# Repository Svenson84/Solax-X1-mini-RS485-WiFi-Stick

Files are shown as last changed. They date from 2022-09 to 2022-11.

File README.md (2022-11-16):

# Solax-X1-mini-RS485-WiFi-Stick

RS485 WiFi Stick is a project to monitor the Solax X1 mini via RS485 interface.  
Optional data can be stored in a InfluxDB.

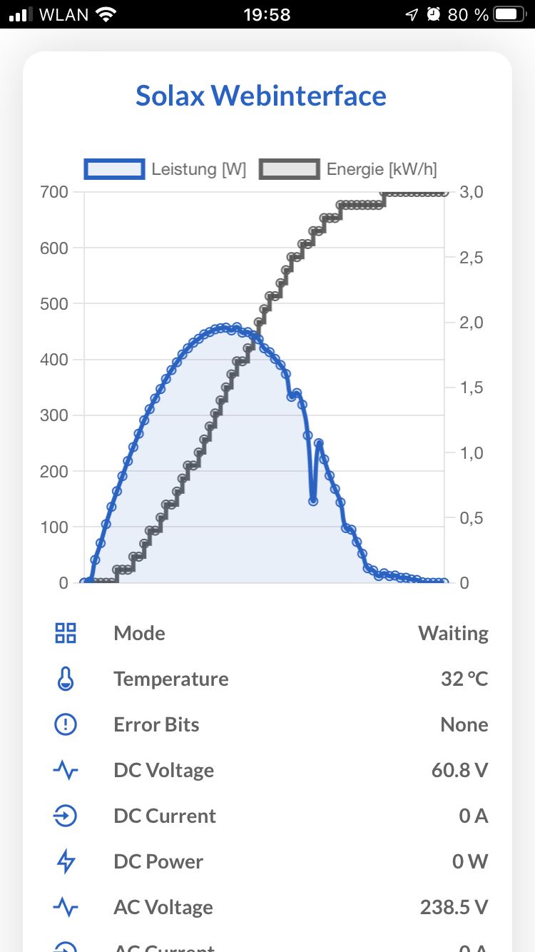
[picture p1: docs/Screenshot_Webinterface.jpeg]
Webinterface


## What it does and what it doesn't?
This software provides a local webinterface via a wifi connection for the "Solax X1 Mini" power inverter.  
An ESP8266 (Wemos D1 mini) with an external RS485 transceiver (MAX 3485) is used as a gateway between the RS485 of the Solax power inverter and your private LAN/WiFi.   
It does only use the RS485 to communicate with the Solax power inverter!  
It does NOT required the official Solax WIFI or LAN stick!  
It does NOT use the Solax cloud connection or Solax API!  
It does NOT require any internet connection!  

## References
This code uses, and/or is partly based on, and/or is inspired by the following projects:  
https://github.com/JensJordan/solaXd  
https://github.com/syssi/esphome-modbus-solax-x1

## Hardware

* ESP8266 (e.g. Wemos D1 mini)
* RS485-to-TTL module with MAX3485
* USB connector / cable
* RJ45 connector / cable
* Optional: Housing

### Connection of RS485-TTL module

```
               RS485                        UART
┌─────────┐              ┌─────────────┐           ┌─────────────────┐
│         │              │          RXD│<--------->│TX               │
│  Solax  │<---- A+ ---->│  RS485    DE│<--\       │       WEMOS D1  │
│ X1 Mini │<---- B- ---->│  to TTL  /RE│<---+----->│D1      ESP8266  │
│         │<--- GND ---->│  module  TXD│<--------->│RX               │
│         │              │             │           │                 │
│         │              │          VCC│<--------->│3.3V          VCC│<--
│         │              │          GND│<--------->│GND           GND│<--
└─────────┘              └─────────────┘           └─────────────────┘
```

### Modification of WEMOS D1 mini board
Serial resistors for TX and RX on the Wemos D1 mini have been removed.  
Remark: I am not sure if it is mandatory to remove thoses resistors. In the beginning i had troubles to get the RS485 working, so i removed thoses resistors and never tested again with populated resistors!  

Be careful: if you remove thoses resistors, a flashing/programming via USB interface of the WEMOS D1 mini is not possible anymore.  
You have to flash the software before removing of the resistors. With flashing the software, also a Over-The-Air  (OTA) will be flashed. Then it is still possible to flash an update via OTA if the resistors have been removed.

### Modification of RS485 board
I was not able to find a RS485 board, that was using the MAX3485 (3.3V version) instead of the regular MAX485 (5V version). 
It might work also with the MAX485, but i used only the MAX3485 - without any issues all the time. 

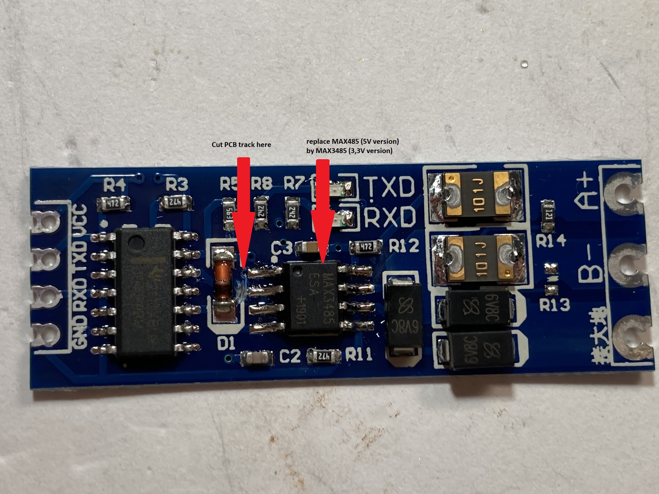
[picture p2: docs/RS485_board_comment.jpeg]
RS485 Board


Originally the DE/RE pins are controlled automatically. By cutting the PCB track and connecting the DE/RE pins to the ESP8266 pin D1 by a single wire, the flow controll is handled by the ESP8266 SW.

### Solax X1 Mini RS485 interface

| Pin | Purpose | RS485-to-TTL pin  | Color T-568B |
| :-----: | :--- | :--- | --- |
| 1 | RefGen | | |
| 2 | Com/DRM0 | | |
| 3 | GND_COM | | |
| 4 | **A+** | **A+** | Blue |
| 5 | **B-** | **B-** | Blue-White |
| 6 | E_Stop | | |
| 7 | **GND_COM**  | **GND** | Brown-White  |
| 8 | -- | | |

## Software

The available code is available for the Arduino IDE and developed with a Wemos D1 mini ESP8266.

### Website
The application uses LittleFS. The Webinterface can also be uploaded directly with the Arduino IDE by a LittleFS file upload to the target hardware. 

### InfluxDB
ToDo

## Mechanical

### Housing

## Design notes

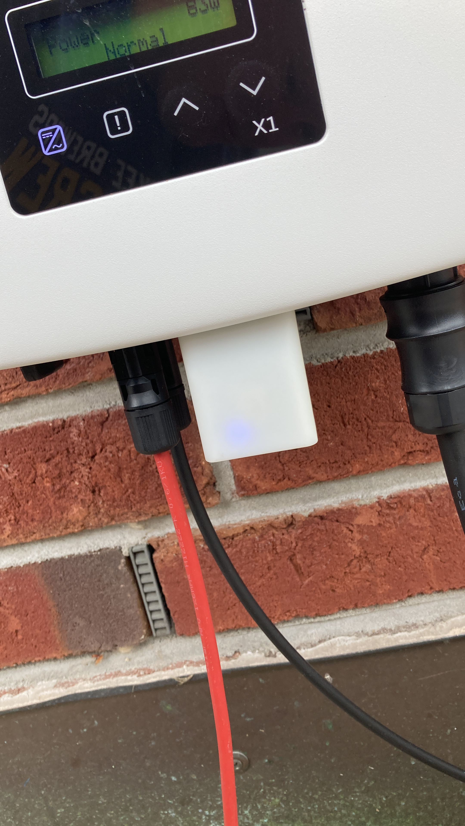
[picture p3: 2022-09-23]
docs/dongle_07.jpeg

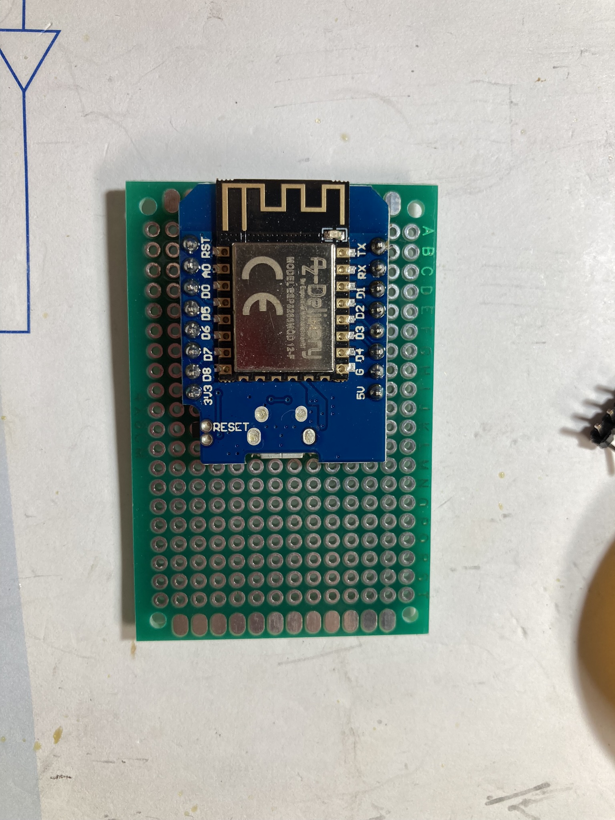
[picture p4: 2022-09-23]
docs/dongle_03.jpeg

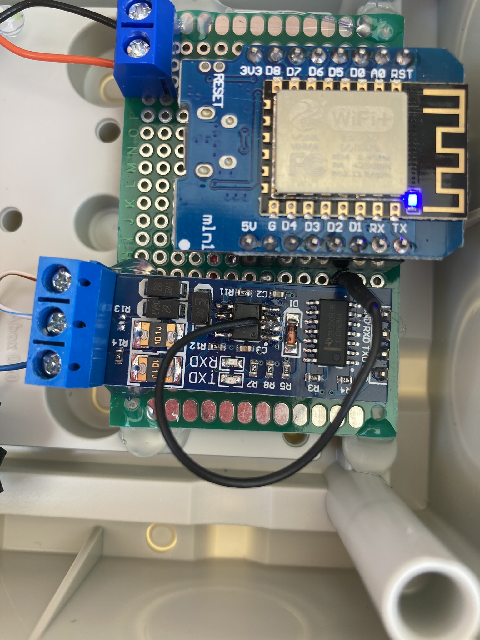
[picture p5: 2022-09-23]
docs/housing_02.jpeg

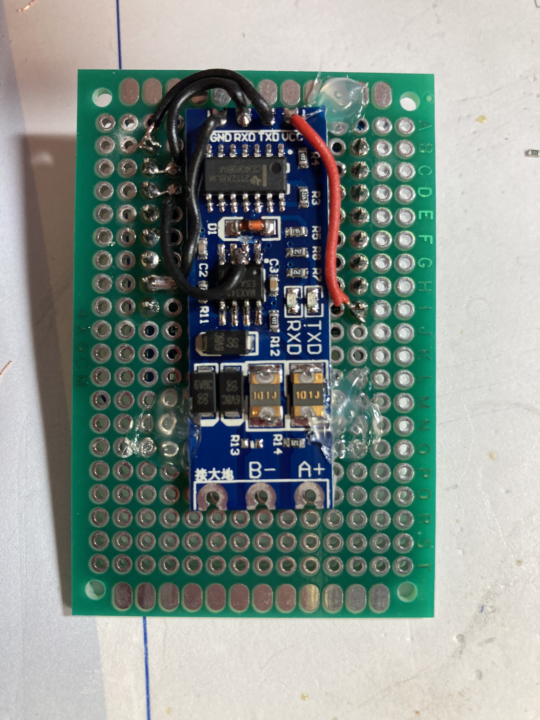
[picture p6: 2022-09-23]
docs/dongle_04.jpeg

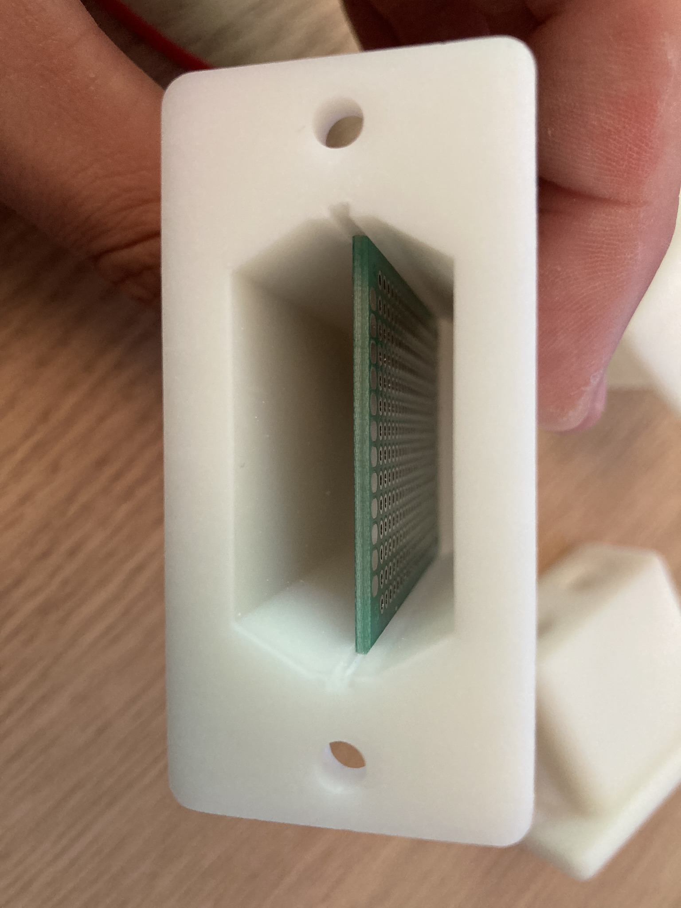
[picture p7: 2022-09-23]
docs/dongle_02.jpeg

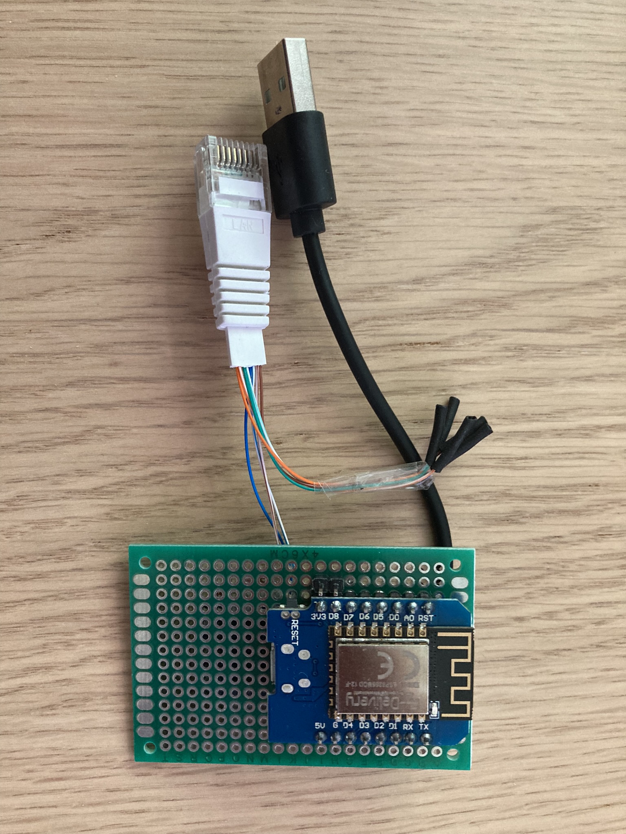
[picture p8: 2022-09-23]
docs/dongle_06.jpeg

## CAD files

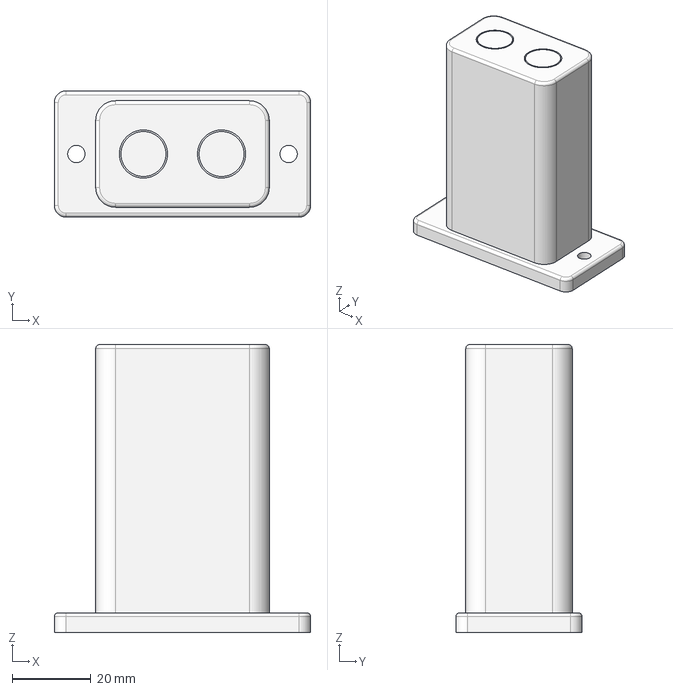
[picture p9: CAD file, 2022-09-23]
CAD/Solax_V3.step
65.0 x 32.0 x 73.0 mm

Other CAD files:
CAD/Solax_V3.FCStd

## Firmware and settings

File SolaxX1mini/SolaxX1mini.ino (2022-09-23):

// This software provides a local webinterface via a wifi connection for the "Solax X1 Mini" power inverter.
// An ESP8266 (Wemos D1 mini) with an external RS485 transceiver (MAX 3485) is used as a gateway between the RS485 of the Solax power inverter and your private LAN/WiFi. 
// It does only use the RS485 to communicate with the Solax power inverter!
// It does NOT required the official Solax WIFI or LAN stick!
// It does NOT use the Solax cloud connection or Solax API! 
// It does NOT require any internet connection!
// 
// This code uses, and/or is partly based on, and/or is inspired by the following projects:
// https://github.com/JensJordan/solaXd
// https://github.com/syssi/esphome-modbus-solax-x1
// https://github.com/chartjs/Chart.js
//
// Using following external data (images, fonts, etc.)
// HTML Launch Picture: https://www.pexels.com/de-de/foto/innovation-erneuerbare-energie-umweltfreundlich-solarplatten-6729421/
// Font: https://fonts.google.com/specimen/Lato#standard-styles
// Icons: https://github.com/Remix-Design/RemixIcon
// FavIcon: https://www.flaticon.com/de/kostenlose-icons/solar
//
// Disclaimer:
// Feel free to use this code on your own risk ;)
//
// Referenced documents:
// REF{1} https://github.com/syssi/esphome-modbus-solax-x1/blob/main/docs/SolaxPower_Single_Phase_External_Communication_Protocol_-_X1_Series_V1.2.pdf
// REF{2} https://www.solaxpower.com/wp-content/uploads/2017/01/X1-Mini-Install-Manual.pdf

#include <Arduino.h>
#include <ESP8266WiFi.h>
#include <ESP8266WebServer.h>
#include <ESP8266HTTPClient.h>
#include <WiFiManager.h>
#include <ArduinoOTA.h>
#include <LittleFS.h>

#include "Solax.h"

#define LED_PIN                       2     // Wemos D1 (D4) = GPIO2 --> On-board LED
#define WIFI_RESET_PIN                13    // Wemos D1 (D7) = GPIO13 --> internal Pull-Up. Add Jumper to GND for Wifi Reset
#define SOLAX_RS485_TX_ENABLE_PIN     5     // Wemos D1 (D1) = GPIO5 --> Transmitter active HIGH, Receiver active LOW
#define HTTP_TIMEOUT_TIME             3     // sec
#define INFLUX_UPDATE_INTERVAL        60    // sec

#define WIFI_HOSTNAME                 "SolaxWifi"
#define WIFI_CONFIG_SSID              "SolaxWifi-Setup"
#define WIFI_CONFIG_PWD               "Solax"
#define OTA_PWD                       "Solax"
#define INFLUX_URI                    "http://192.168.0.123:8086/write?db=MyDatabase"
#define INFLUX_USER                   "username"
#define INFLUX_PASS                   "password"
#define INFLUX_CLIENT_ID              "ESP8266"
#define INFLUX_TABLE                  "Solax"

Solax Inverter(SOLAX_RS485_TX_ENABLE_PIN);
WiFiManager wifiManager;
ESP8266WebServer WebServer(80);
WiFiClient WifiClient;

bool wifiReset = false;
bool espReboot = false;
uint8_t retryCnt = 0;

uint32_t Now = 0;
uint32_t uptime_seconds = 0;

int32_t WiFiRSSI = 0;
int32_t WiFiReconnects = 0;


void UpdateInfluxDB() {
  static uint32_t LastTime = 0;

  Now = millis();
  if(Inverter.Data.Active == true && (Now - LastTime) > (INFLUX_UPDATE_INTERVAL * 1000U)) {
    LastTime = Now;
    if (WiFi.status() == WL_CONNECTED) {
      HTTPClient http;
   
      http.begin(WifiClient, INFLUX_URI);
      http.setAuthorization(INFLUX_USER, INFLUX_PASS);
      http.addHeader("User-Agent", INFLUX_CLIENT_ID);
      http.addHeader("Connection", "close");
      http.addHeader("Content-Type", "application/x-www-form-urlencoded");

      String msg;
      msg += String(INFLUX_TABLE) + ",source=" + String(INFLUX_CLIENT_ID) + " ";
      msg += "RSSI="+String(WiFiRSSI);
      msg += ",Temperature="+String(Inverter.Data.Temperature);
      msg += ",PV1Voltage="+String(Inverter.Data.PV1Voltage/10.0);
      msg += ",PV1Current="+String(Inverter.Data.PV1Current/10.0);
      msg += ",CurrentOutput="+String(Inverter.Data.CurrentOutput/10.0);
      //msg += ",GridVoltage="+String(Inverter.Data.GridVoltage);
      //msg += ",GridFrequency="+String(Inverter.Data.GridFrequency);
      //msg += ",PowerOutput="+String(Inverter.Data.PowerOutput);
      msg += ",PowerOutput="+String(Inverter.Data.AvgPowerOutput);
      msg += ",InverterMode="+String(Inverter.Data.InverterMode);
      msg += ",YieldToday="+String(Inverter.Data.YieldToday/10.0);
      msg += ",YieldTotal="+String(Inverter.Data.YieldTotal/10.0);


      int httpCode = http.POST(msg);
      if (httpCode == 204) {
        // [UpdateInfluxDB] Update successful
        // HTTP Status 204: Success, no Content
        // nothing to do
        retryCnt = 0;
      }
      else {
        // [UpdateInfluxDB] Update failed
        retryCnt++;
        if(retryCnt >= 3) espReboot = true;
      }

      http.end();
    }
  }
}

void status_led(uint8_t on) {
  if(on) {
    digitalWrite(LED_PIN, LOW);
  }
  else {
    digitalWrite(LED_PIN, HIGH);
  }
}

void UptimeUpdate() {
  static uint16_t delta_millis = 0;
  static uint32_t last_update = 0;

  Now = millis();
  delta_millis += (Now - last_update);
  last_update = Now;
  
  while(delta_millis >= 1000) {
    uptime_seconds++;
    delta_millis -= 1000;
  }
}

void CheckWifiStatus() {
  bool res;
  if (WiFi.status() != WL_CONNECTED) {
    // WiFi connection lost... try to reconnect!
    res = wifiManager.autoConnect(WIFI_CONFIG_SSID, WIFI_CONFIG_PWD);
    if(!res) {
      status_led(false);
    } 
    else {
      status_led(true);
      WiFiReconnects++;
    }
  }
  else {
	  WiFiRSSI = WiFi.RSSI();
  }
}

void SendJsonIdInfo() {
  String json = "{\n";
  json += "  \"NotUsed0\": " + String(Inverter.Info.NotUsed[0]) + ",\n";
  json += "  \"NotUsed1\": " + String(Inverter.Info.NotUsed[1]) + ",\n";
  json += "  \"NotUsed2\": " + String(Inverter.Info.NotUsed[2]) + ",\n";
  json += "  \"NotUsed3\": " + String(Inverter.Info.NotUsed[3]) + ",\n";
  json += "  \"NotUsed4\": " + String(Inverter.Info.NotUsed[4]) + ",\n";
  json += "  \"NotUsed5\": " + String(Inverter.Info.NotUsed[5]) + ",\n";
  json += "  \"NotUsed6\": " + String(Inverter.Info.NotUsed[6]) + ",\n";
  json += "  \"NotUsed7\": " + String(Inverter.Info.NotUsed[7]) + ",\n";
  json += "  \"NotUsed8\": " + String(Inverter.Info.NotUsed[8]) + ",\n";
  json += "  \"Phases\": " + String(Inverter.Info.Phases) + ",\n";
  json += "  \"RatedPower\": \"" + String(Inverter.Info.RatedPower) + "\",\n";
  json += "  \"FirmwareVer\": \"" + String(Inverter.Info.FirmwareVer) + "\",\n";
  json += "  \"ModuleName\": \"" + String(Inverter.Info.ModuleName) + "\",\n";
  json += "  \"FactoryName\": \"" + String(Inverter.Info.FactoryName) + "\",\n";
  json += "  \"SerialNumber\": \"" + String(Inverter.Info.SerialNumber) + "\",\n";
  json += "  \"RatedBusVoltage\": \"" + String(Inverter.Info.RatedBusVoltage) + "\n";
  json += "}";
  
  WebServer.send(200, "application/json", json);
}


void SendJsonStatus() {
  String json = "{\n";

  json += "  \"mode_name\": \"";
  switch(Inverter.Data.InverterMode) { 
    case 0: json += "Waiting"; break;
    case 1: json += "Checking"; break;
    case 2: json += "On-Grid"; break;
    case 3: json += "Fault"; break;
    default: json += "Unkown"; break;
  }
  json += "\",\n";

  json += "  \"mode\": " + String(Inverter.Data.InverterMode) + ",\n";
  json += "  \"temperature\": " + String(Inverter.Data.Temperature) + ",\n";

  json += "  \"error_bits\": \"";
  if(Inverter.Data.ErrorMessage == 0) json += "None";
  else {
    // Error Byte 0
    if((Inverter.Data.ErrorMessage & (1 << 0)) == true) json += "TzProtectFault ";
    if((Inverter.Data.ErrorMessage & (1 << 1)) == true) json += "MainsLostFault ";
    if((Inverter.Data.ErrorMessage & (1 << 2)) == true) json += "GridVoltFault ";
    if((Inverter.Data.ErrorMessage & (1 << 3)) == true) json += "GridFreqFault ";
    if((Inverter.Data.ErrorMessage & (1 << 4)) == true) json += "PLLLostFault ";
    if((Inverter.Data.ErrorMessage & (1 << 5)) == true) json += "BusVoltFault ";
    if((Inverter.Data.ErrorMessage & (1 << 6)) == true) json += "BIT06 ";
    if((Inverter.Data.ErrorMessage & (1 << 7)) == true) json += "OciFault ";
    // Error Byte 1
    if((Inverter.Data.ErrorMessage & (1 << 8)) == true) json += "DciOCPFault ";
    if((Inverter.Data.ErrorMessage & (1 << 9)) == true) json += "ResidualCurrentFault ";
    if((Inverter.Data.ErrorMessage & (1 << 10)) == true) json += "PvVoltFault ";
    if((Inverter.Data.ErrorMessage & (1 << 11)) == true) json += "Ac10MinsVoltageFault ";
    if((Inverter.Data.ErrorMessage & (1 << 12)) == true) json += "IsolationFault ";
    if((Inverter.Data.ErrorMessage & (1 << 13)) == true) json += "TemperatureOverFault ";
    if((Inverter.Data.ErrorMessage & (1 << 14)) == true) json += "FanFault ";
    if((Inverter.Data.ErrorMessage & (1 << 15)) == true) json += "BIT15 ";
    // Error Byte 2
    if((Inverter.Data.ErrorMessage & (1 << 16)) == true) json += "SpiCommsFault ";
    if((Inverter.Data.ErrorMessage & (1 << 17)) == true) json += "SciCommsFault ";
    if((Inverter.Data.ErrorMessage & (1 << 18)) == true) json += "BIT18 ";
    if((Inverter.Data.ErrorMessage & (1 << 19)) == true) json += "InputConfigFault ";
    if((Inverter.Data.ErrorMessage & (1 << 20)) == true) json += "EepromFault ";
    if((Inverter.Data.ErrorMessage & (1 << 21)) == true) json += "RelayFault ";
    if((Inverter.Data.ErrorMessage & (1 << 22)) == true) json += "SampleConsistenceFault ";
    if((Inverter.Data.ErrorMessage & (1 << 23)) == true) json += "ResidualCurrentDeviceFault ";
    // Error Byte 3
    if((Inverter.Data.ErrorMessage & (1 << 24)) == true) json += "BIT24 ";
    if((Inverter.Data.ErrorMessage & (1 << 25)) == true) json += "BIT25 ";
    if((Inverter.Data.ErrorMessage & (1 << 26)) == true) json += "BIT26 ";
    if((Inverter.Data.ErrorMessage & (1 << 27)) == true) json += "BIT27 ";
    if((Inverter.Data.ErrorMessage & (1 << 28)) == true) json += "BIT28 ";
    if((Inverter.Data.ErrorMessage & (1 << 29)) == true) json += "DCIDeviceFault ";
    if((Inverter.Data.ErrorMessage & (1 << 30)) == true) json += "OtherDeviceFault ";
    if((Inverter.Data.ErrorMessage & (1 << 31)) == true) json += "BIT31 ";
  }
  json += "\",\n";
  
  json += "  \"dc_voltage\": " + String(Inverter.Data.PV1Voltage / 10.0) + ",\n";
  json += "  \"dc_current\": " + String(Inverter.Data.PV1Current / 10.0) + ",\n";
  json += "  \"ac_voltage\": " + String(Inverter.Data.GridVoltage / 10.0) + ",\n";
  json += "  \"ac_current\": " + String(Inverter.Data.CurrentOutput / 10.0) + ",\n";
  json += "  \"ac_frequency\": " + String(Inverter.Data.GridFrequency / 100.0) + ",\n";
  json += "  \"ac_power\": " + String(Inverter.Data.PowerOutput) + ",\n";
  json += "  \"avg_ac_power\": " + String(Inverter.Data.AvgPowerOutput) + ",\n";
  json += "  \"max_ac_power\": " + String(Inverter.Data.MaxPowerOutput) + ",\n";
  json += "  \"stat_ac_power\": [";
  if(Inverter.Stat_Idx > 0) {
    for (int i=0; i<(Inverter.Stat_Idx-1); i++) {
      json += String(Inverter.Stat_AvgPower[i]) + ", ";
    }
    json += String(Inverter.Stat_AvgPower[Inverter.Stat_Idx-1]);
  }
  json += "],\n";
  json += "  \"energy_today\": " + String(Inverter.Data.YieldToday / 10.0) + ",\n";
  json += "  \"stat_energy_today\": [";
  if(Inverter.Stat_Idx > 0) {
    for (int i=0; i<(Inverter.Stat_Idx-1); i++) {
      json += String(Inverter.Stat_PwrToday[i]) + ", ";
    }
    json += String(Inverter.Stat_PwrToday[Inverter.Stat_Idx-1]);
  }
  json += "],\n";
  json += "  \"energy_total\": " + String(Inverter.Data.YieldTotal / 10.0) + ",\n";
  json += "  \"runtime\": " + String(uptime_seconds) + ",\n";
  json += "  \"runtime_total\": " + String(Inverter.Data.RuntimeTotal) + ",\n";
  json += "  \"wifi_ssid\": \"" + String(WiFi.SSID()) + "\",\n";
  json += "  \"wifi_ip\": \"" + WiFi.localIP().toString() + "\",\n";
  json += "  \"wifi_rssi\": " + String(WiFiRSSI) + ",\n";
  json += "  \"wifi_reconnects\": " + String(WiFiReconnects) + "\n";
  json += "}";

  WebServer.send(200, "application/json", json);
}

void handleRoot(){
  WebServer.sendHeader("Location", "/index.html", true);
  WebServer.send(302, "text/plain","");
}
 
void handleWebRequests(){
  String file;
  String type;
  String uri = WebServer.uri();

  if(uri.startsWith("/update.json")) {
    SendJsonStatus();
  }
  else if(uri.startsWith("/IdInfo.json")) {
    SendJsonIdInfo();
  }
  else {
    if(uri.startsWith("/index.html")) {
      file = "index.html";
      type = "text/html";
    }
    else if(uri.startsWith("/solax.css")) {
      file = "solax.css";
      type = "text/css";
    }
    else if(uri.startsWith("/remixicon.css")) {
      file = "remixicon.css";
      type = "text/css";
    }
    else if(uri.startsWith("/remixicon.eot")) {
      file = "remixicon.eot";
      type = "font/eot";
    }
    else if(uri.startsWith("/remixicon.ttf")) {
      file = "remixicon.ttf";
      type = "font/ttf";
    }
    else if(uri.startsWith("/remixicon.woff")) {
      file = "remixicon.woff";
      type = "font/woff";
    }
    else if(uri.startsWith("/remixicon.woff2")) {
      file = "remixicon.woff2";
      type = "font/woff2";
    }
    else if(uri.startsWith("/Lato-Regular.ttf")) {
      file = "Lato-Regular.ttf";
      type = "font/ttf";
    }
    else if(uri.startsWith("/Lato-Bold.ttf")) {
      file = "Lato-Bold.ttf";
      type = "font/ttf";
    }
    else if(uri.startsWith("/solax.js")) {
      file = "solax.js";
      type = "application/javascript";
    }
    else if(uri.startsWith("/chart.min.js")) {
      file = "chart.min.js";
      type = "application/javascript";
    }
    else if(uri.startsWith("/favicon.ico")) {
      file = "favicon.ico";
      type = "image/x-icon";
    }
    else if(uri.startsWith("/touch-icon-iphone.png")) {
      file = "touch-icon-iphone.png";
      type = "image/png";
    }
    
    if(file != "") {
      File dataFile = LittleFS.open(file, "r");
      if (WebServer.hasArg("download")) type = "application/octet-stream";
      if(dataFile) {
        WebServer.streamFile(dataFile, type);
      }
      dataFile.close();
    }
    else {
      String message = "404 - invalid request!\n";
      WebServer.send(404, "text/plain", message);
    }
  }
}


void setup() { 
  Inverter.begin();  

  // Configure GPIO pin for wifi reset input
  pinMode(WIFI_RESET_PIN, INPUT_PULLUP);

  // Configure GPIO pin for status LED
  pinMode(LED_PIN, OUTPUT);
  status_led(false);

  // Check if reset of wifi data is requested by pulling WIFI_RESET_PIN to GND
  if(digitalRead(WIFI_RESET_PIN) == 0) {
    wifiManager.resetSettings();
    while(1) {  
      delay(100);
      status_led(true);
      delay(100);
      status_led(false);
    }
  }

  //WiFi.mode(WIFI_STA); // explicitly set mode, esp defaults to STA+AP
  wifiManager.setDebugOutput(false);
  wifiManager.setHostname(WIFI_HOSTNAME);
	wifiManager.setEnableConfigPortal(true);
  wifiManager.setWiFiAutoReconnect(false);
	wifiManager.setCleanConnect(true);
	wifiManager.setConnectRetries(10);
	wifiManager.setConnectTimeout(6);

  bool res;
  //res = wifiManager.autoConnect(WIFI_CONFIG_SSID, WIFI_CONFIG_PWD);
  res = wifiManager.autoConnect(WIFI_CONFIG_SSID);
  if(!res) {
    // Failed to connect... reboot!
    ESP.restart();
  }
  
  // WiFi connected!
  status_led(true);
  
  //ArduinoOTA.setPassword(OTA_PWD);
  ArduinoOTA.setHostname(WIFI_HOSTNAME);
  ArduinoOTA.begin();
  
  LittleFS.begin();
  //LittleFS.format();

  WebServer.on("/", handleRoot);
  WebServer.onNotFound(handleWebRequests);
  WebServer.begin();
} 
 
void loop() {
  if(wifiReset) {
    wifiManager.resetSettings();
    wifiManager.reboot();
  }

  if(espReboot) {
    ESP.restart();
  }

  ArduinoOTA.handle();
  UptimeUpdate();
  CheckWifiStatus();
  Inverter.loop();
  UpdateInfluxDB();
  WebServer.handleClient();
}

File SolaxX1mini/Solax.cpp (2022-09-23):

#include <Arduino.h>
#include "Solax.h"

Solax::Solax(uint8_t pin)
{
  TxEnablePin = pin;
  RxByteCnt = 0;
  
  RxBuffer = {0};
  Data = {0};
  
  Data.Address = SOLAX_INVERTER_ADDRESS;
  Data.Active = false;
}

void Solax::begin(void) {
  // Configure Serial Port for communication with Solax X1 Mini via RS485
  Serial.setTimeout(1000);  
  Serial.begin(9600, SERIAL_8N1); // SERIAL_8N1 (default) --> 8 data bits, No parity, 1 stop bit

  // Configure GPIO Pin for activation of RS485 transmitter
  pinMode(TxEnablePin, OUTPUT);
  digitalWrite(TxEnablePin, LOW); 
}

void Solax::loop(void) {
  const uint32_t now = millis();
  static uint32_t LastRequest = 0;
  static uint32_t LastRxByte = 0;
  static uint8_t request_toggle = 0;
  
  if((now - LastRxByte) > SOLAX_RS485_INTER_CHAR_DELAY) {
    ClearRxBuffer();
  }

  if((now - LastRxByte) > (SOLAX_RS485_INVERTER_TIMEOUT * 1000U)) {
    Data.Active = false;
  }

  // Send Request to Inverter (Tx Message)
  if((now - LastRequest) > SOLAX_RS485_REQUEST_CYCLE) {
    switch(request_toggle) {
      case 0:
        DiscoverDevice();
        break;
        
      case 1:
        RequestNormalData(Data.Address);
        break;
        
      case 2:
        //RequestIdData(Data.Address); // TODO: this is not really working 
        break;

      default:
        break;
    }
    
    if(request_toggle >= 2) {
      request_toggle = 0;
    }
    else {
      request_toggle++;
    }

    LastRequest = now;
  }

  delay(5);
  
  // Read Response from Inverter (Rx Message)
  while (Serial.available()) {
    uint8_t byte;
    byte = Serial.read();
    LastRxByte = millis();
    if (GetMsg(byte)) {
      /*String text = "[ModbusSolaxLoop] New RX msg complete: " + String(RxBuffer.Header[1], HEX) + " " + String(RxBuffer.Header[0], HEX) + " " + String(RxBuffer.Source[1], HEX) + " " + String(RxBuffer.Source[0], HEX) + " " + String(RxBuffer.Destination[1], HEX) + " " + String(RxBuffer.Destination[0], HEX) + " " + String(RxBuffer.ControlCode, HEX) + " " + String(RxBuffer.FunctionCode, HEX) + " " + String(RxBuffer.DataLength, HEX);
      for(int i = 0; i<RxBuffer.DataLength; i++) {
        text += " " + String(RxBuffer.Data[i], HEX);
      }
      text += " " + String(RxBuffer.Checksum[1], HEX);
      text += " " + String(RxBuffer.Checksum[0], HEX);
      //Debug(text);
      */
      
      if(ProcessRxMsg()) {
        //Debug("[ModbusSolaxLoop] RX msg processed");

        //Send timestamp of last received byte via RS485 DebugMsg
        //uint8_t data[64];
        //data[0] = (uint8_t) (LastRxByte >> 24) & 0xff;
        //data[1] = (uint8_t) (LastRxByte >> 16) & 0xff;
        //data[2] = (uint8_t) (LastRxByte >> 8) & 0xff;
        //data[3] = (uint8_t) (LastRxByte) & 0xff;
        //SolaxTxMsg_Debug(data);
      }
    } 
    else {
      //ClearRxBuffer();
      //Debug("[RS485] Read Byte: "+ String(byte, HEX) + ", " + String(RxByteCnt));
    }
  }
}


void Solax::ClearRxBuffer(void) {
  RxByteCnt = 0;
}

// Function: GetMsg()
//  Stores received byte from RS485 in the RX Buffer.
// Parameter:
//  uint8_t byte: Provide new byte from RS485 interface.
// Return:
//  bool: TRUE if RS485 message from header to checksum was completely received.
//        FALSE if RS485 message is still incomplete or new byte was invalid.
bool Solax::GetMsg(uint8_t byte) {
  RxByteCnt++;
  
  // Byte 1: Header MSB (0xAA)
  if(RxByteCnt == 1) {
    if(byte == 0xAA) {
      RxBuffer.Header[1] = byte;
    }
    else {
      //Debug("[SolaxGetMsg] Invalid Header MSB: 0x" + String(byte, HEX));
      ClearRxBuffer();
    }
    return(false);
  }
  
  // Byte 2: Header LSB (0x55)
  if(RxByteCnt == 2) {
    if(byte == 0x55) {
      RxBuffer.Header[0] = byte;
    }
    else {
      //Debug("[SolaxGetMsg] Invalid Header LSB: 0x" + String(byte, HEX));
      ClearRxBuffer();
    }
    return(false);
  }
  
  // Byte 3: Source Address MSB
  // acc. REF{1}, table in chapter 4: Source Address MSB should be zero for packets from the inverter
  if(RxByteCnt == 3) {
    if(byte == 0x00) {
      RxBuffer.Source[1] = byte;
    }
    else {
      //Debug("[SolaxGetMsg] Invalid Source Address MSB: 0x" + String(byte, HEX));
      ClearRxBuffer();
    }
    return(false);
  }

  // Byte 4: Source Address LSB 
  // acc. REF{1}, table in chapter 4: Source Address LSB should contain the Inverter Address for incoming packets 
  // For unregistered inverters the value is 0x00 or 0xff ??
  if(RxByteCnt == 4) {
    RxBuffer.Source[0] = byte;
    return(false);
  }
  
  // Byte 5: Destination Address MSB
  // acc. REF{1}, table in chapter 4: Destination Address MSB should contain Gateway Adress (AP) for incoming packets 
  if(RxByteCnt == 5) {
    if(byte == SOLAX_GATEWAY_ADDRESS) {
      RxBuffer.Destination[1] = byte;
    }
    else {
      //Debug("[SolaxGetMsg] Invalid Destination Address MSB: 0x" + String(byte, HEX));
      ClearRxBuffer();
    }
    return(false);
  }

  // Byte 6: Destination Address LSB
  // acc. REF{1}, table in chapter 4: Destination Address LSB should be zero for incoming packets 
  if(RxByteCnt == 6) {
    if(byte == 0x00) { 
      RxBuffer.Destination[0] = byte;
    }
    else {
      //Debug("[SolaxGetMsg] Invalid Destination Address LSB: 0x" + String(byte, HEX));
      ClearRxBuffer();
    }
    return(false);
  }

  // Byte 7: Control Byte
  if(RxByteCnt == 7) {
    RxBuffer.ControlCode = byte;
    return(false);
  }
  
  // Byte 8: Function Code
  if(RxByteCnt == 8) {
    RxBuffer.FunctionCode = byte;
    return(false);
  }
  
  // Byte 9: Data Length (N)
  if(RxByteCnt == 9) {
    RxBuffer.DataLength = byte;
    return(false);
  }

  // Byte 10...(10+N-1): Data Bytes
  if(RxByteCnt >= 10 && RxByteCnt <= (10 + RxBuffer.DataLength - 1)) {
    RxBuffer.Data[RxByteCnt - 10] = byte;
    return(false);
  }
  
  // Byte 10+N: Checksum MSB
  if(RxByteCnt == (10 + RxBuffer.DataLength)) {
    RxBuffer.Checksum[1] = byte;
    return(false);
  }

  // Byte 10+N+1: Checksum LSB
  if(RxByteCnt == (10 + RxBuffer.DataLength + 1)) {
    // Message completely received!
    RxBuffer.Checksum[0] = byte; 

    // Check Checksum
    uint16_t ReceivedChecksum = (uint16_t) RxBuffer.Checksum[1] << 8 | (uint16_t) RxBuffer.Checksum[0];
    uint16_t CalculatedChecksum = CalcChecksum(RxBuffer);
    if (ReceivedChecksum != CalculatedChecksum) {
      //Debug("[SolaxGetMsg] Incorrect Checksum: 0x" + String(ReceivedChecksum, HEX) + " (Expected: 0x" + String(CalculatedChecksum, HEX) + ")");
      return(false);
    }
  }
  else {
    //Debug("[SolaxGetMsg] Byte read invalid");
    ClearRxBuffer();
    return(false);
  }

  return(true);
}
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
